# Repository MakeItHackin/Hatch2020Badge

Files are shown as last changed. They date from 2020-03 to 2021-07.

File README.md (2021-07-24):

# Hatch2020Badge

Thank you for being interested in this year's Hudson Alpha Tech Challenge Badge!!!  

View my YouTube video for a quick demo and overview:  
https://www.youtube.com/watch?v=0dqjWGFenuU

The badges were designed by @makeithackin and sponsored by Hudson Alpha.  

More information will come after HATCH weekend.  

The badge is in the shape of the Hudson Alpha logo.  It features a fully functioning circuit if you would like to solder components onto the top surface.  Using a 555 timer and a 4017 Decade Counter, the 10 LEDs will flash one by one.  Using the "speed" switch, the user can either pick a slow or fast blinking mode for the LEDs.  

If you have any questions or comments, please initiate an 'Issue' on github and I will answer as soon as I can.

Below are the components that can be soldered onto the badge for functionality:
CR2032 Battery and Holder
555 Timer
4017 Decade Counter
100 ohm 0805 resistors 
0805 LEDs
Two switches
Two capacitors (for changing speed)
Two 22kohm resistors for 555 timer

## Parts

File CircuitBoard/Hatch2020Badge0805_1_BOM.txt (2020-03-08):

Partlist exported from C:/Users/Andrew/Documents/EAGLE/projects/HATCH2020Badge/Hatch2020Badge0805_1.sch at 3/8/2020 4:19 PM

Part    Value          Device         Package    Description                POPULARITY SPICEPREFIX
C1      22u            C-USC0805      C0805      CAPACITOR, American symbol 63         C          
C2      4.7u           C-USC0805      C0805      CAPACITOR, American symbol 63         C          
IC1     4017D          4017D          SO16       COUNTER/DIVIDER            0                     
IC2     LM555D         LM555D         SO08       TIMER                                            
LED_A1                 LEDSML0805     SML0805    LED                        17                    
LED_A2                 LEDSML0805     SML0805    LED                        17                    
LED_A3                 LEDSML0805     SML0805    LED                        17                    
LED_A4                 LEDSML0805     SML0805    LED                        17                    
LED_A5                 LEDSML0805     SML0805    LED                        17                    
LED_A6                 LEDSML0805     SML0805    LED                        17                    
LED_A7                 LEDSML0805     SML0805    LED                        17                    
LED_A8                 LEDSML0805     SML0805    LED                        17                    
LED_A9                 LEDSML0805     SML0805    LED                        17                    
LED_A10                LEDSML0805     SML0805    LED                        17                    
POWER   3PINSWITCHMINI 3PINSWITCHMINI 3PINMINI                                                    
R1      22k            R-US_R0805     R0805      RESISTOR, American symbol  85         R          
R4      22k            R-US_R0805     R0805      RESISTOR, American symbol  85         R          
R13     100            R-US_R0805     R0805      RESISTOR, American symbol  85         R          
R14     100            R-US_R0805     R0805      RESISTOR, American symbol  85         R          
R15     100            R-US_R0805     R0805      RESISTOR, American symbol  85         R          
R16     100            R-US_R0805     R0805      RESISTOR, American symbol  85         R          
R17     100            R-US_R0805     R0805      RESISTOR, American symbol  85         R          
R18     100            R-US_R0805     R0805      RESISTOR, American symbol  85         R          
R19     100            R-US_R0805     R0805      RESISTOR, American symbol  85         R          
R20     100            R-US_R0805     R0805      RESISTOR, American symbol  85         R          
R21     100            R-US_R0805     R0805      RESISTOR, American symbol  85         R          
R22     100            R-US_R0805     R0805      RESISTOR, American symbol  85         R          
SPEED   3PINSWITCHMINI 3PINSWITCHMINI 3PINMINI                                                    
U$1     2032NO_FP      2032NO_FP      2032_NO_FP

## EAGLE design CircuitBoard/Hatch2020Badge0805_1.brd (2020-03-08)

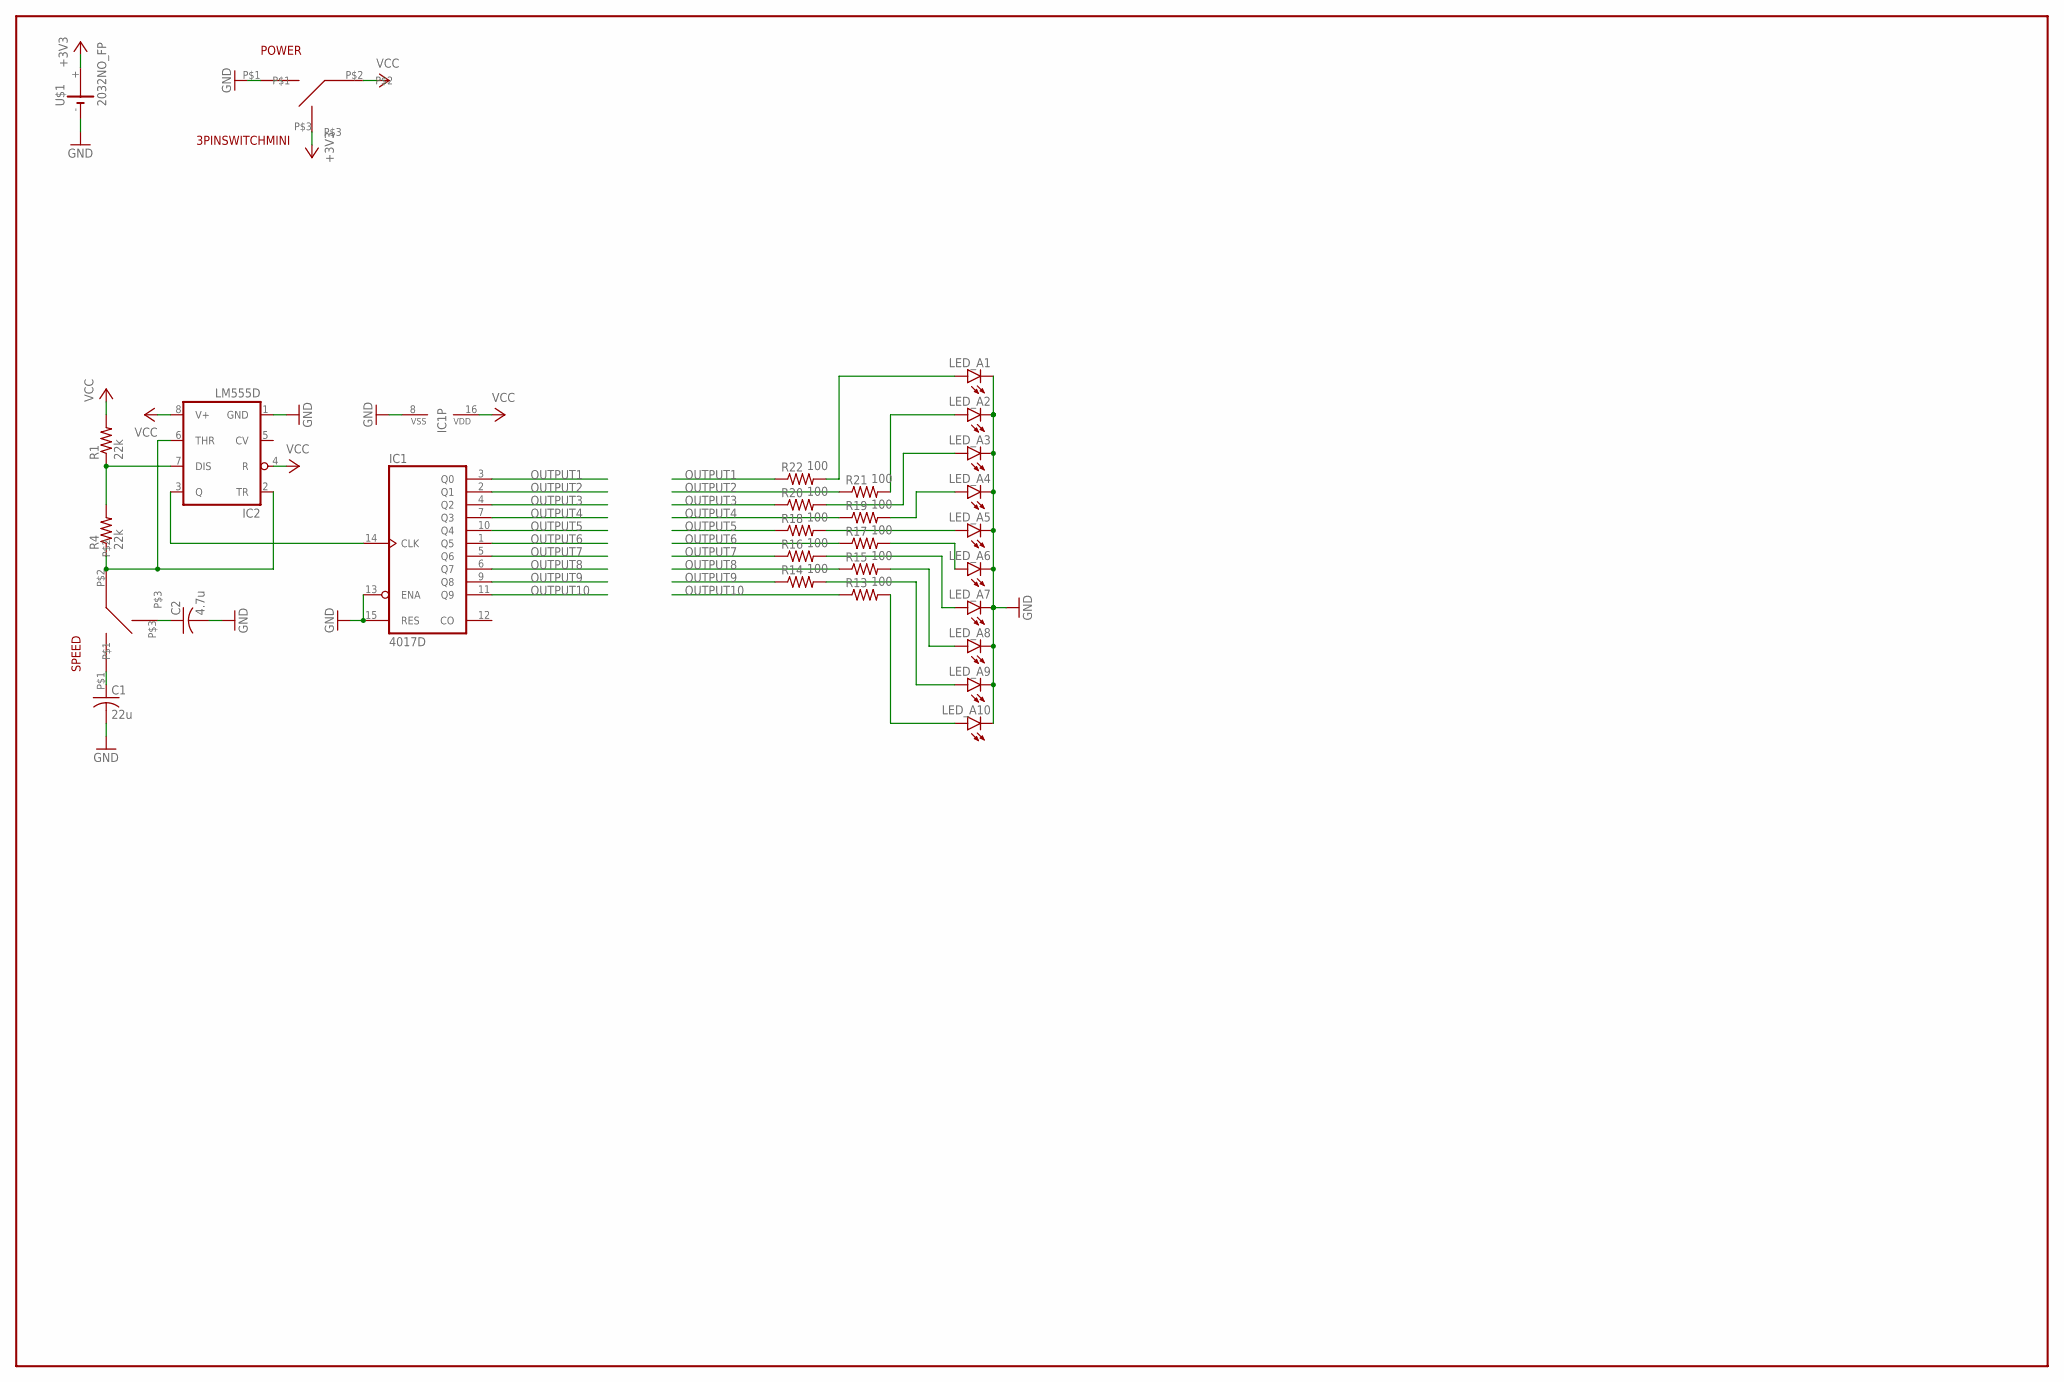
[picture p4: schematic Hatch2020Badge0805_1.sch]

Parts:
C1: 22u; C0805
C2: 4.7u; C0805
IC1: 4017D; SO16
IC2: LM555D; SO08
LED_A1, LED_A2, LED_A3, LED_A4, LED_A5, LED_A6, LED_A7, LED_A8, LED_A9, LED_A10: LEDSML0805; SML0805
POWER: 3PINSWITCHMINI; 3PINMINI
R1, R4: 22k; R0805
R13, R14, R15, R16, R17, R18, R19, R20, R21, R22: 100; R0805
SPEED: 3PINSWITCHMINI; 3PINMINI
U$1: 2032NO_FP; 2032_NO_FP

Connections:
+3V3: POWER.P$3, U$1.+
GND: C1.2, C2.2, IC1.8 (VSS), IC1.13 (ENA), IC1.15 (RES), IC2.1 (GND), LED_A1.C, LED_A2.C, LED_A3.C, LED_A4.C, LED_A5.C, LED_A6.C, LED_A7.C, LED_A8.C, LED_A9.C, LED_A10.C, POWER.P$1, U$1.-
unnamed: IC2.7 (DIS), R1.1, R4.2
unnamed: LED_A2.A, R21.2
unnamed: LED_A3.A, R20.2
unnamed: C1.1, SPEED.P$1
unnamed: C2.1, SPEED.P$3
unnamed: LED_A1.A, R22.2
unnamed: LED_A4.A, R19.2
unnamed: LED_A5.A, R18.2
unnamed: LED_A6.A, R17.2
unnamed: LED_A7.A, R16.2
unnamed: LED_A8.A, R15.2
unnamed: LED_A9.A, R14.2
unnamed: LED_A10.A, R13.2
unnamed: IC2.2 (TR), IC2.6 (THR), R4.1, SPEED.P$2
unnamed: IC1.14 (CLK), IC2.3 (Q)
OUTPUT1: IC1.3 (Q0), R22.1
OUTPUT2: IC1.2 (Q1), R21.1
OUTPUT3: IC1.4 (Q2), R20.1
OUTPUT4: IC1.7 (Q3), R19.1
OUTPUT5: IC1.10 (Q4), R18.1
OUTPUT6: IC1.1 (Q5), R17.1
OUTPUT7: IC1.5 (Q6), R16.1
OUTPUT8: IC1.6 (Q7), R15.1
OUTPUT9: IC1.9 (Q8), R14.1
OUTPUT10: IC1.11 (Q9), R13.1
VCC: IC1.16 (VDD), IC2.4 (R), IC2.8 (V+), POWER.P$2, R1.2

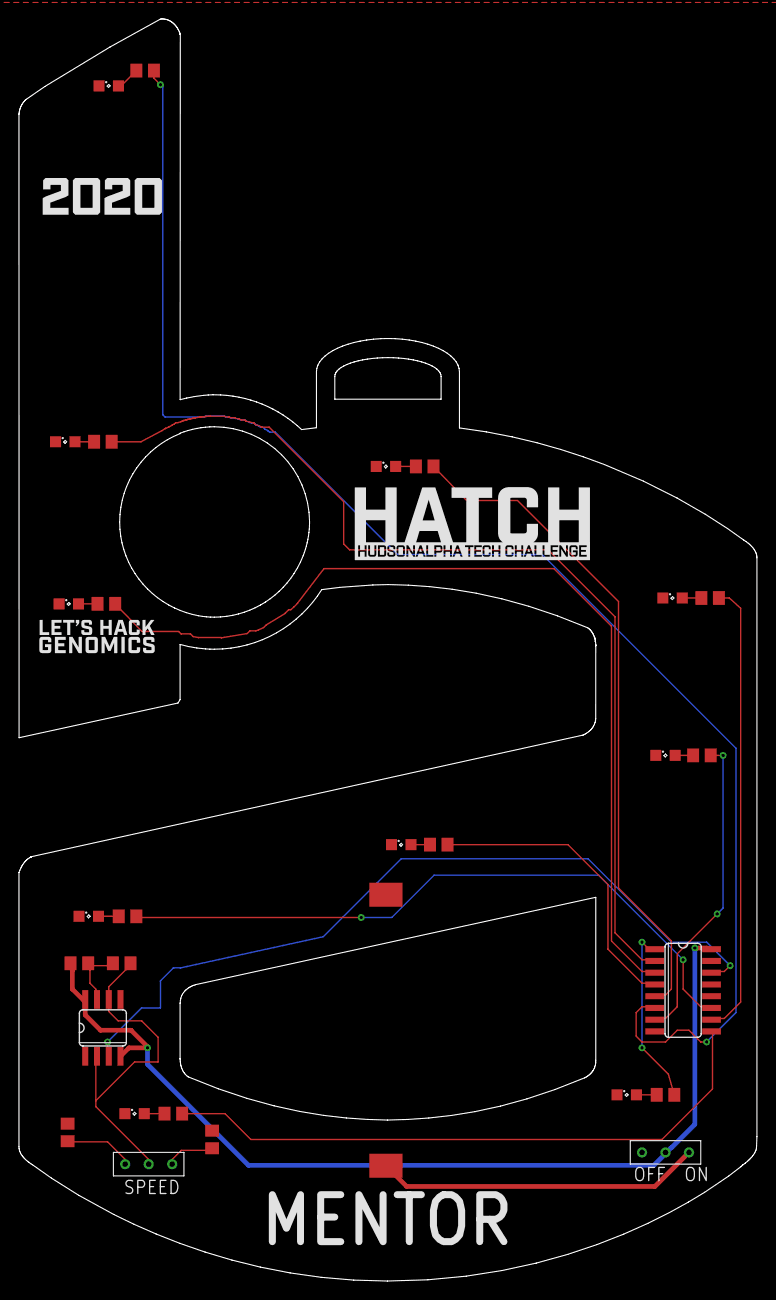
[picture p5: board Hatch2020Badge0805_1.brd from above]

Board: 2 copper layers, 79.8 x 136.5 mm, 29 parts (0 on the bottom side), 28 nets.
